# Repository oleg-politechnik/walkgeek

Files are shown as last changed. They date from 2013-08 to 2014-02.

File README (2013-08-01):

= About walkgeek ===============================================================

This is walkgeek, another portable music player based upon STM32F4-Discovery
board hardware, which contains STM32F407VGT6 microcontroller and CS43L22 audio
codec. For now, it can play MP3 and Opus files.

The goal of this project is to create a fully functional yet very simple
portable player, optimized for easy navigation across a lot of pretty long audio
files (podcasts).

= Hardware =====================================================================

There are 2 pretty similar HW platforms supported (or rather variations of a
one platform) called N1100 and F4DISCOVERY.

--- F4DISCOVERY ----------------------------------------------------------------

This platform is represented by STM32F4-Discovery board. It gives you an easy
way to try out and develop walkgeek. No HW modifications are necessary in a very
basic case. You only need to put some audio files supported by walkgeek on a USB
Flash drive and attach in to the USB Micro connector (CN5). User interface is
limited to a on-board "User" button which acts as button "3", and 4 leds:
 - Red means no Flash drive connected;
 - Green means Flash drive has enumerated and Player is started;
 - Orange means Player is stopped or loading current track;
 - Blue (blinking) means Player is playing current track.

--- N1100 ----------------------------------------------------------------------

There is also a more portable HW version that fits into Nokia 1100 cell phone
case. Design resources for it are also available in a pcb/ directory of this
project in EAGLE CAD format.

= Software =====================================================================

1. Checkout the latest version of the source code by following the instructions
   here: http://code.google.com/p/walkgeek/source/checkout

2. In order to build the source code, you need:
 - Git
 - CMake of a version of 2.8.4 or higher.
 - ARM GNU Toolchain: CodeSourcery, Linaro, etc.
 
3. You probably will find useful to have openocd as a gdb server which supports
   many cheap JTAG probes, including STLink v2 which is found in all the
   Discovery boards by ST.

= Example steps for Linux-based desktop ========================================

1. Checkout latest version of player's source code.

$ git clone 

2. It seems that CMake doesn't like embedded arm gnu toolchains (which is the
   case for at least CodeSourcery and Linaro on Ubuntu GNU/Linux) and shows
   errors at the project configure stage. You may solve them by typing: 

$ cd walkgeek
$ sudo ./patch_cmake.sh

   Dollar sign stands for command line prompt, do not type it.
   Please note that on OS other than GNU/Linux it may be different file or even
   may be unnecessary. Probably there is more proper way but this one has worked
   for me.

3. You should be at this moment in walkgeek directory. Type:

$ mkdir Build
$ cd Build

4. Next step is to invoke cmake in order to generate Makefiles. You can specify
   a list of parameters where syntax for each item is -D%param_name%=%param_value%.
   Among other standard cmake parameters, you can specify:
   - TOOLCHAIN_PREFIX -- full path to the root directory of your toolchain.
     Default is $ENV{HOME}/Local/gcc-arm-none-eabi-4_6-2012q2
   - TARGET_TRIPLET -- prefic for toolchain programs, default is arm-none-eabi.
   - STM32_USBLib_DIR -- full path to the STM32 USB Host Device Lib.
     Default is ${CMAKE_SOURCE_DIR}/bsp/3rd_party/STM32_USB-Host-Device_Lib_V2.1.0
   - CMAKE_BUILD_TYPE -- Release or Debug or others (please refer to the CMake
     documentation). Default is Debug.

   - PLATFORM -- choose one of the supported HW platforms: N1100, F4DISCOVERY,
     SIMULATOR (see below). Default is N1100.
   - PROFILING -- enable measurement of the CPU consumption of the audio codecs.
     1 enables, 0 disables. Default is 0.
   - ENABLE_TRACE -- enable trace() functions output via USB CDC. Default is 0.
   - USE_MP3 -- enable MP3 support. Default is 0.
   - RPROG_OHM -- if your platform is N1100, this is the value of resistor
     which sets LTC4054 charge current. Default is 2000.
   - SD_CARD_FILE -- if your platform is SIMULATOR, enter a full path to the
     file which contains FAT file system. See below for details. No default here.

   So if your toolchain and paths are the same, you don't need to specify all of
   them. In this example the default values are passed explicitly.

$ cmake -DTOOLCHAIN_PREFIX=/home/oleg/Local/CodeSourcery/Sourcery_CodeBench_Lite_for_ARM_EABI \
-DUSE_MP3=1 ../ -G"Unix Makefiles"

$ make

   Now you can build .hex, .bin or .dis (disassembly) files

$ make walkgeek.hex

   My Ubuntu even auto-completes Makefile targets.

6. (Optional) You can also debug it. Open one console, cd to the walkgeek's
   source root dir and

$ openocd -f openocd_luminary.cfg

   Switch to another console, cd to the walkgeek's source root dir and

$ arm-none-eabi-gdb --quiet --tui -x debug.gdb

= SIMULATOR ====================================================================

  There's a way to launch walkgeek on your PC (currently only POSIX OS'es are
  supported, at least GNU/Linux). PCM Audio output is not yet implemented.
  But console IO works and keyboard is simulated via stdin (just press a key
  and hit enter). If you press a number of keys and press enter, each of them
  will be handled consequently. Also, SD card IO simulation works, so that
  FAT FS module of walkgeek sees no difference compared to real HW. The idea is
  to manually create a file of some MB of a size, create FAT FS inside it
  (just like if it were an SD card), mount it, put some audio or whatever files
  in it and feed it to walkgeek application.

1. To do it, first create a file (this example will create a
   bs*count=128 MB file)

 $ dd if=/dev/zero of=sd_card.bin bs=1024 count=131072
 
2. Make FAT FS here
 
 $ /sbin/mkdosfs -F 16 sd_card.bin
 
3. Mount it
 
 $ mkdir fatmount
 $ sudo mount -t vfat -o umask=0000 -o loop sd_card.bin fatmount
 
4. Put some files into fatmount/ dir.

5. Unmount it in order to drain write buffers.

 $ sudo umount fatmount

6. When launching CMake (see above), choose -DPLATFORM=SIMULATOR -D%path-to%/sd_card.bin

  This is a good way to debug higher-level algorithms (for example, Navigator
  module was tested that way).

Thank you for your attention.

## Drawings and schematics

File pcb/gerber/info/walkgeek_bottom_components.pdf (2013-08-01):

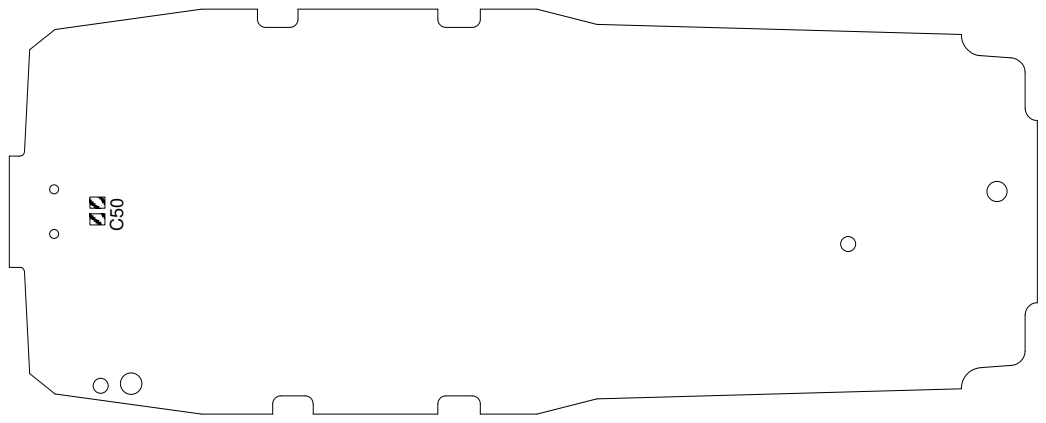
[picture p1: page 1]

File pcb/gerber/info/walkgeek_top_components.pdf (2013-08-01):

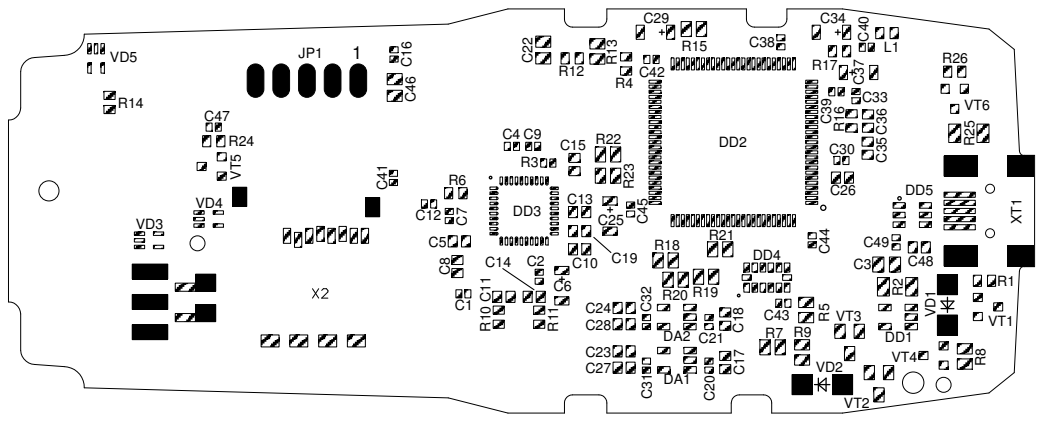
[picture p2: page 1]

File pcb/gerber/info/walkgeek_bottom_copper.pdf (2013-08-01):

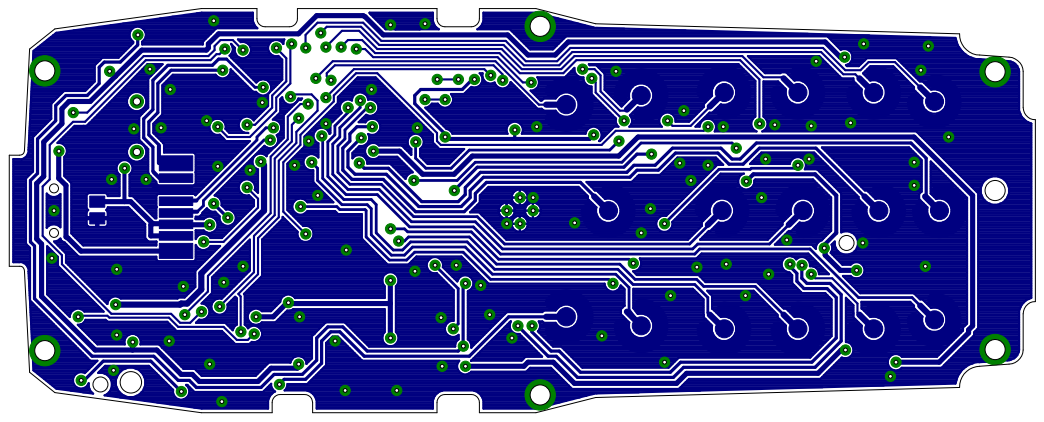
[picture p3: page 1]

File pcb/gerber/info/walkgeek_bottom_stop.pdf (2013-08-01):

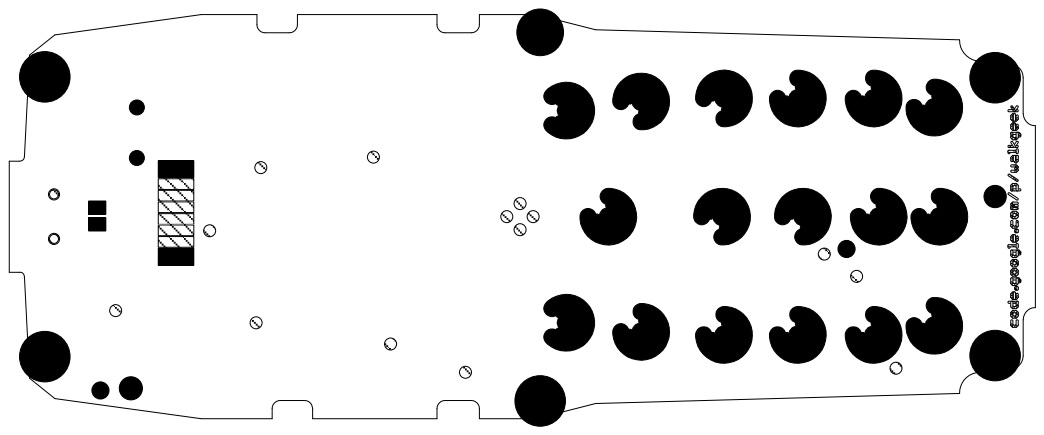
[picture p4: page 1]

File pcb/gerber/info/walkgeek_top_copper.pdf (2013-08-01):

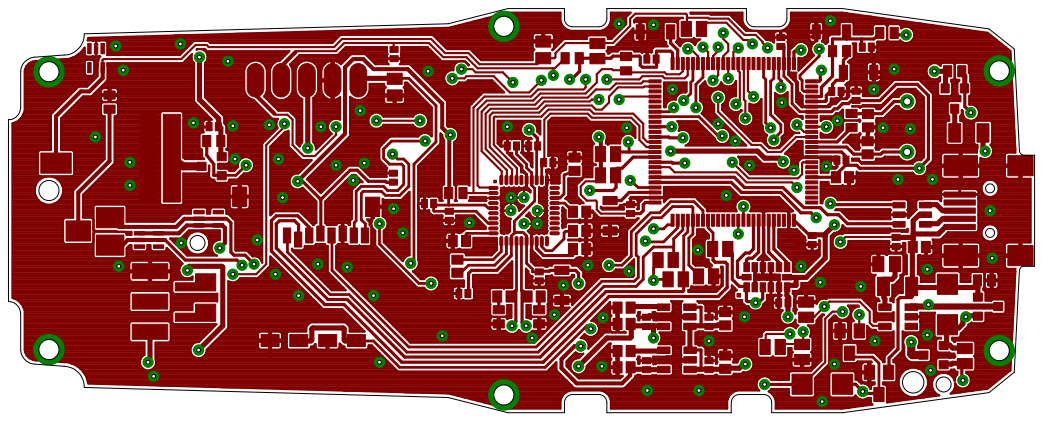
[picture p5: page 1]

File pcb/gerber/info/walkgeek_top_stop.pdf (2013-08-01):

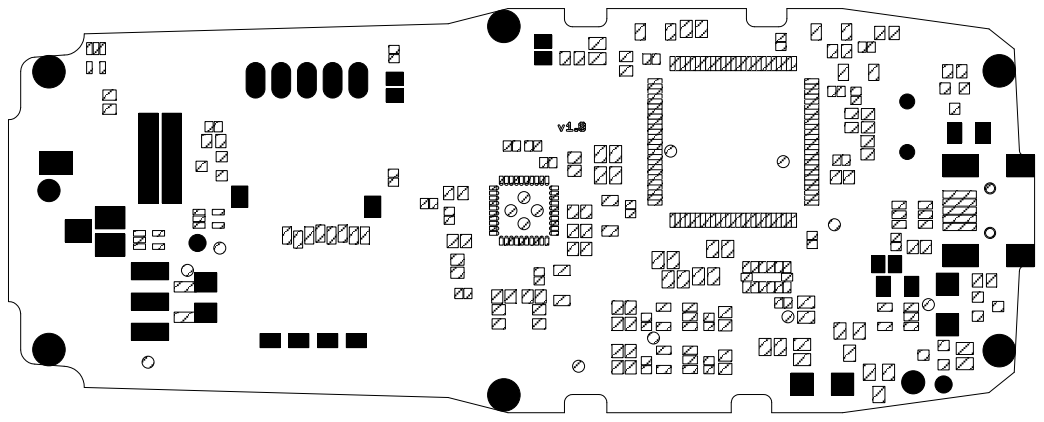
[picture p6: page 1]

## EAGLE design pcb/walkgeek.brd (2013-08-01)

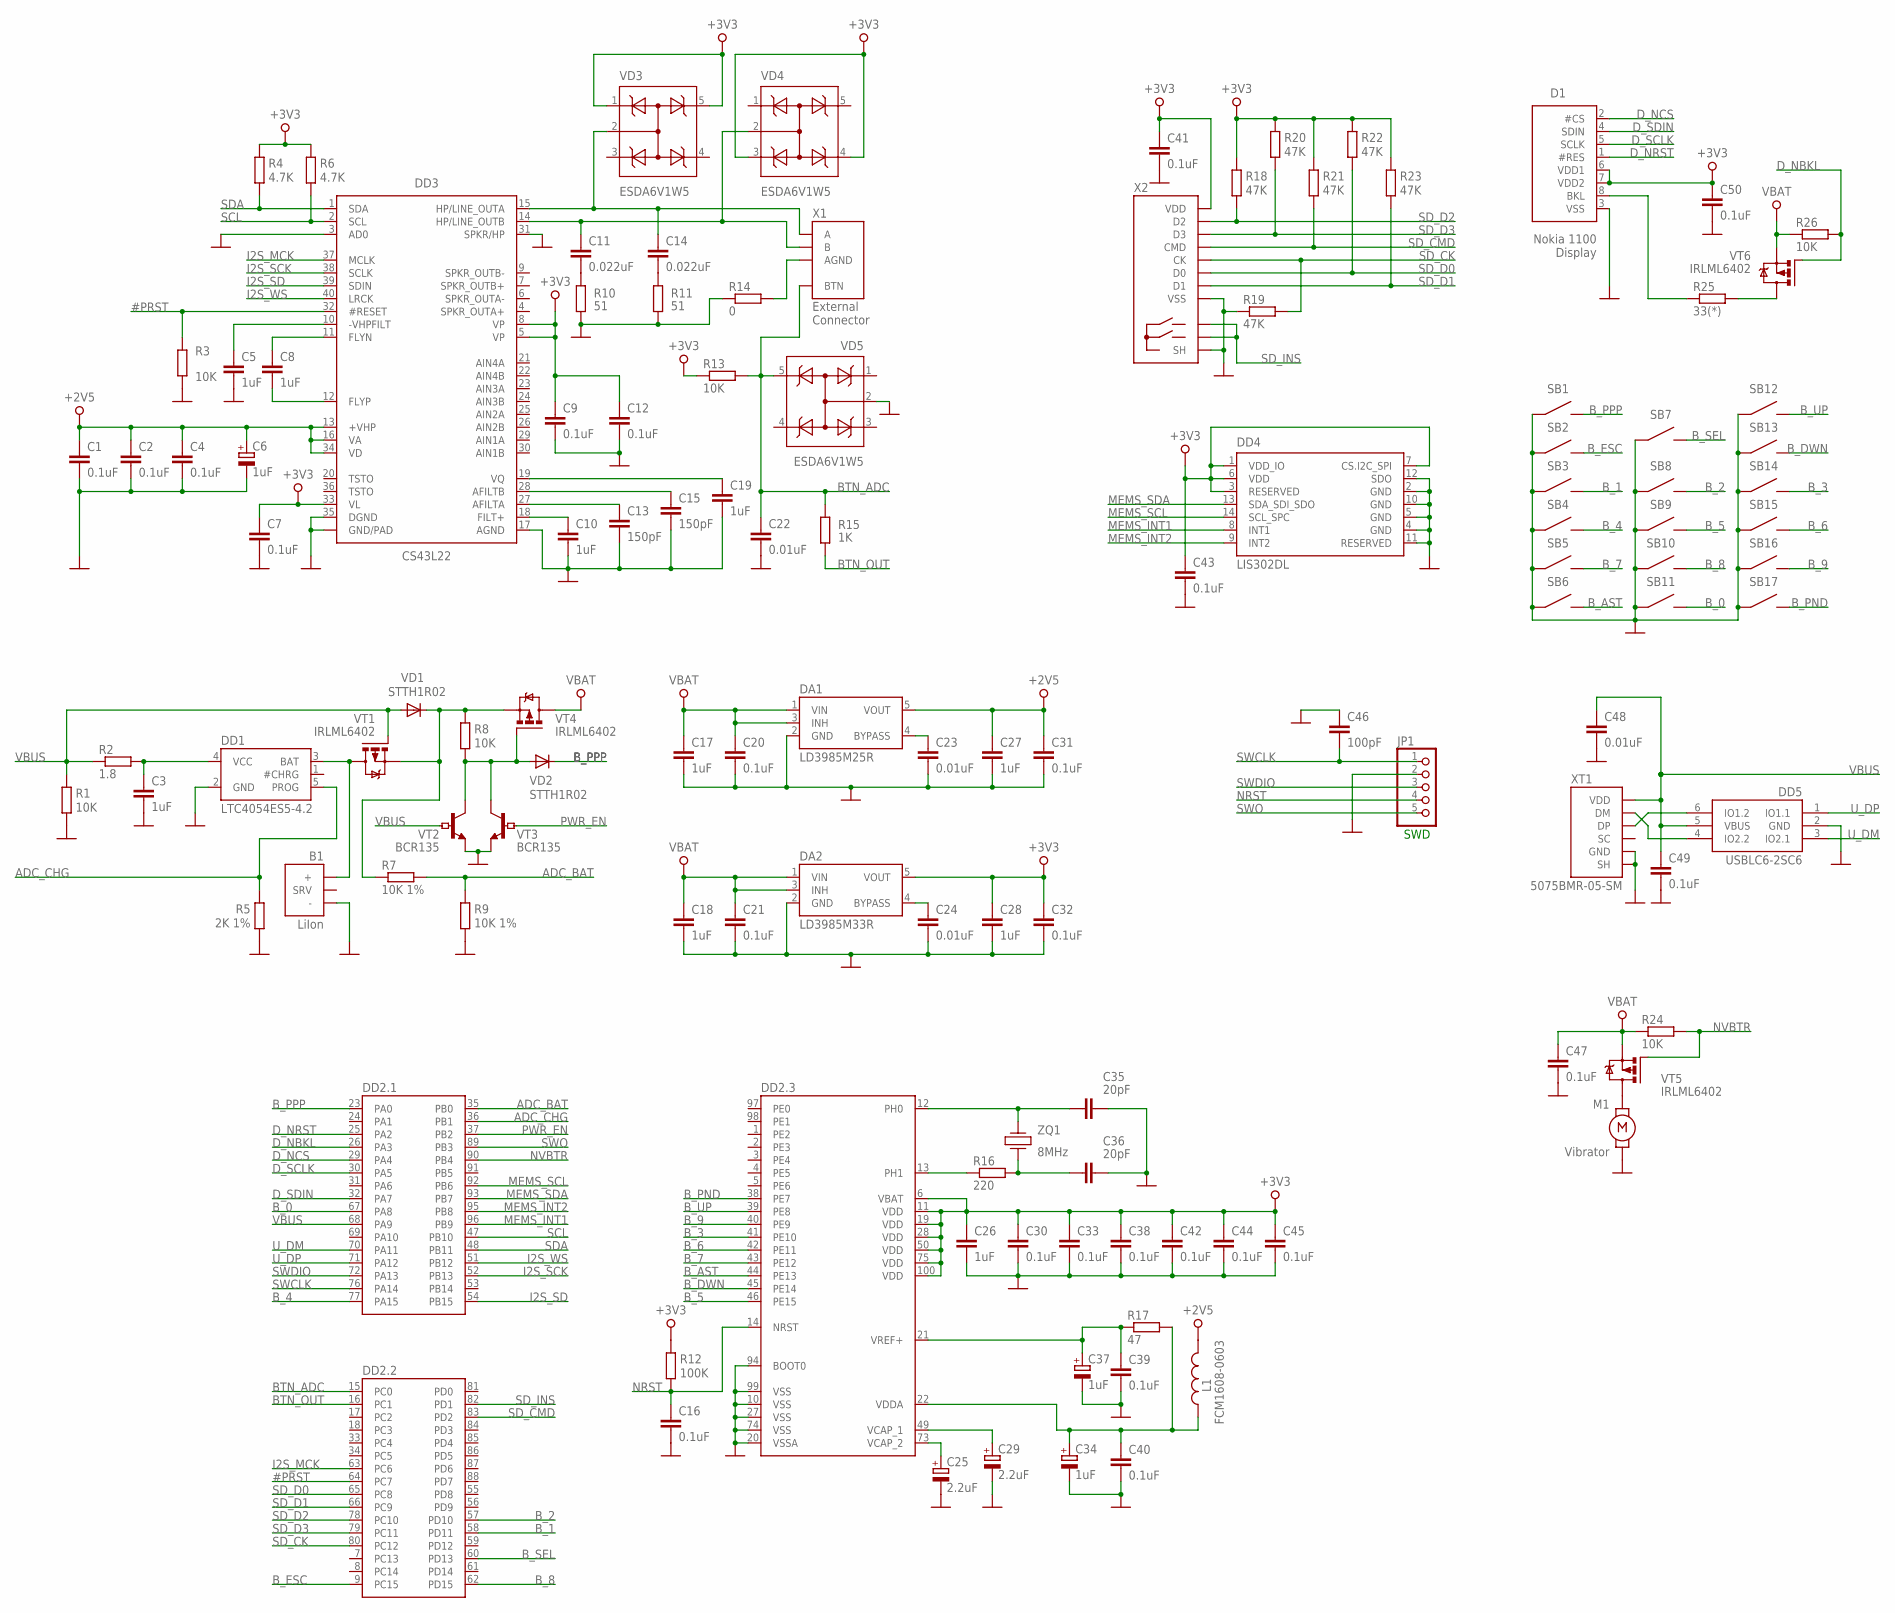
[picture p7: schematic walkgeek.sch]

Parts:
B1: NOKIA1100_BATTERY_CONN
C1, C2, C4, C7, C9, C12, C16, C20, C21, C30, C31, C32, C33, C38, C39, C40, C41, C42, C43, C44, C45, C47, C49: 0.1uF; C0402
C3: 1uF; C0805
C5, C8, C10, C17, C18, C19, C26, C27, C28: 1uF; C0603
C6, C34, C37: 1uF; SMC_A
C11, C14: 0.022uF; C0603
C13, C15: 150pF; C0603
C22: 0.01uF; C0805
C23, C24, C48: 0.01uF; C0603
C25, C29: 2.2uF; SMC_A
C35, C36: 20pF; C0603
C46: 100pF; C0805
C50: 0.1uF; C0805
D1: NOKIA1100_DISP
DA1: LD3985M25R; TSOT23-5
DA2: LD3985M33R; TSOT23-5
DD1: LTC4054ES5-4.2; TSOT23-5
DD2: STM32F4XXVXT; LQFP100
DD3: CS43L22; QFN40-6X6
DD4: LIS302DL; LGA14
DD5: USBLC6-2SC6; SOT23-6L
JP1: PINHD-1X5; 1X05/90_FLAT
L1: FCM1608-0603; R0603
M1: NOKIA1100_VIBRATOR
R1, R24, R26: 10K; R0603
R2: 1.8; R1206
R3: 10K; R0402
R4, R6: 4.7K; R0603
R5: 2K 1%; R0805
R7, R9: 10K 1%; R0805
R8, R13: 10K; R0805
R10, R11: 51; R0603
R12: 100K; R0603
R14: 0; R0603
R15: 1K; R0805
R16: 220; R0603
R17: 47; R0603
R18, R19, R20, R21, R22, R23: 47K; R0805
R25: 33(*); R1206
SB1, SB2, SB3, SB4, SB5, SB6, SB7, SB8, SB9, SB10, SB11, SB12, SB13, SB14, SB15, SB16, SB17: NOKIA1100_KEY_PAD_0
VD1, VD2: STTH1R02; SMA
VD3, VD4, VD5: ESDA6V1W5; SOT323-5L
VT1, VT4, VT5, VT6: IRLML6402; MICRO3
VT2, VT3: BCR135; SOT23-BEC
X1: NOKIA1100_EXT_CONN
X2: MICROSD_CONN; TFC-WPCE-08
XT1: 5075BMR-05-SM; 32005-201
ZQ1: 8MHz; QUARTZ_5MM

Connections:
#PRST: DD2.64 (PC7), DD3.32 (#RESET), R3.2
+2V5: C1.1, C2.1, C4.1, C6.+, C27.1, C31.1, DA1.5 (VOUT), DD3.13 (+VHP), DD3.16 (VA), DD3.34 (VD), L1.1
+3V3: C7.1, C9.1, C12.1, C26.1, C28.1, C30.1, C32.1, C33.1, C38.1, C41.1, C42.1, C43.1, C44.1, C45.1, C50.1, D1.6 (VDD1), D1.7 (VDD2), DA2.5 (VOUT), DD2.6 (VBAT), DD2.11 (VDD), DD2.19 (VDD), DD2.28 (VDD), DD2.50 (VDD), DD2.75 (VDD), DD2.100 (VDD), DD3.5 (VP), DD3.8 (VP), DD3.33 (VL), DD4.1 (VDD_IO), DD4.3 (RESERVED), DD4.6 (VDD), DD4.7 (CS.I2C_SPI), R4.2, R6.2, R12.2, R13.1, R18.2, R20.2, R21.2, R22.2, R23.2, VD3.1, VD3.5, VD4.3, VD4.4, X2.VDD
ADC_BAT: DD2.35 (PB0), R7.2, R9.2
ADC_CHG: DD1.5 (PROG), DD2.36 (PB1), R5.2
BTN_ADC: C22.1, DD2.15 (PC0), R13.2, R15.2, VD5.5, X1.BTN
BTN_OUT: DD2.16 (PC1), R15.1
B_0: DD2.67 (PA8), SB11.INNER
B_1: DD2.58 (PD11), SB3.INNER
B_2: DD2.57 (PD10), SB8.INNER
B_3: DD2.41 (PE10), SB14.INNER
B_4: DD2.77 (PA15), SB4.INNER
B_5: DD2.46 (PE15), SB9.INNER
B_6: DD2.42 (PE11), SB15.INNER
B_7: DD2.43 (PE12), SB5.INNER
B_8: DD2.62 (PD15), SB10.INNER
B_9: DD2.40 (PE9), SB16.INNER
B_AST: DD2.44 (PE13), SB6.INNER
B_DWN: DD2.45 (PE14), SB13.INNER
B_ESC: DD2.9 (PC15), SB2.INNER
B_PND: DD2.38 (PE7), SB17.INNER
B_PPP: DD2.23 (PA0), SB1.INNER, VD2.C
B_SEL: DD2.60 (PD13), SB7.INNER
B_UP: DD2.39 (PE8), SB12.INNER
D_NBKL: DD2.26 (PA3), R26.2, VT6.1 (G)
D_NCS: D1.2 (#CS), DD2.29 (PA4)
D_NRST: D1.1 (#RES), DD2.25 (PA2)
D_SCLK: D1.5 (SCLK), DD2.30 (PA5)
D_SDIN: D1.4 (SDIN), DD2.32 (PA7)
GND: B1.-, C1.2, C2.2, C3.2, C4.2, C5.2, C6.-, C7.2, C9.2, C10.2, C12.2, C13.2, C15.2, C16.2, C17.2, C18.2, C19.2, C20.2, C21.2, C22.2, C23.2, C24.2, C25.-, C26.2, C27.2, C28.2, C29.-, C30.2, C31.2, C32.2, C33.2, C34.-, C35.2, C36.2, C37.-, C38.2, C39.2, C40.2, C41.2, C42.2, C43.2, C44.2, C45.2, C46.1, C47.2, C48.2, C49.2, C50.2, D1.3 (VSS), DA1.2 (GND), DA2.2 (GND), DD1.2 (GND), DD2.10 (VSS), DD2.20 (VSSA), DD2.27 (VSS), DD2.74 (VSS), DD2.94 (BOOT0), DD2.99 (VSS), DD3.3 (AD0), DD3.17 (AGND), DD3.31 (SPKR/HP), DD3.35 (DGND), DD3.EXP@3 (GND/PAD), DD3.EXP@4 (GND/PAD), DD3.EXP@5 (GND/PAD), DD3.EXP@9 (GND/PAD), DD4.2 (GND), DD4.4 (GND), DD4.5 (GND), DD4.10 (GND), DD4.11 (RESERVED), DD4.12 (SDO), DD5.2 (GND), JP1.2, M1.2, R1.1, R3.1, R5.1, R9.1, R10.1, R11.1, R14.1, R19.1, SB1.OUTER, SB1.OUTER1 (OUTER), SB2.OUTER, SB2.OUTER1 (OUTER), SB3.OUTER, SB3.OUTER1 (OUTER), SB4.OUTER, SB4.OUTER1 (OUTER), SB5.OUTER, SB5.OUTER1 (OUTER), SB6.OUTER, SB6.OUTER1 (OUTER), SB7.OUTER, SB7.OUTER1 (OUTER), SB8.OUTER, SB8.OUTER1 (OUTER), SB9.OUTER, SB9.OUTER1 (OUTER), SB10.OUTER, SB10.OUTER1 (OUTER), SB11.OUTER, SB11.OUTER1 (OUTER), SB12.OUTER, SB12.OUTER1 (OUTER), SB13.OUTER, SB13.OUTER1 (OUTER), SB14.OUTER, SB14.OUTER1 (OUTER), SB15.OUTER, SB15.OUTER1 (OUTER), SB16.OUTER, SB16.OUTER1 (OUTER), SB17.OUTER, SB17.OUTER1 (OUTER), VD5.2, VT2.E, VT3.E, X2.SH1 (SH), X2.SH2 (SH), X2.SH3 (SH), X2.SH4 (SH), X2.VSS, XT1.5 (GND), XT1.M1 (SH), XT1.M2 (SH), XT1.M3 (SH), XT1.M4 (SH)
I2S_MCK: DD2.63 (PC6), DD3.37 (MCLK)
I2S_SCK: DD2.52 (PB13), DD3.38 (SCLK)
I2S_SD: DD2.54 (PB15), DD3.39 (SDIN)
I2S_WS: DD2.51 (PB12), DD3.40 (LRCK)
MEMS_INT1: DD2.96 (PB9), DD4.8 (INT1)
MEMS_INT2: DD2.95 (PB8), DD4.9 (INT2)
MEMS_SCL: DD2.92 (PB6), DD4.14 (SCL_SPC)
MEMS_SDA: DD2.93 (PB7), DD4.13 (SDA_SDI_SDO)
unnamed: D1.8 (BKL), R25.1
unnamed: C10.1, DD3.18 (FILT+)
unnamed: C13.1, DD3.27 (AFILTA)
unnamed: C15.1, DD3.28 (AFILTB)
unnamed: C19.1, DD3.19 (VQ)
unnamed: C11.1, DD3.14 (HP/LINE_OUTB), VD4.2, X1.B
unnamed: C14.1, DD3.15 (HP/LINE_OUTA), VD3.2, X1.A
unnamed: C8.1, DD3.11 (FLYN)
unnamed: C8.2, DD3.12 (FLYP)
unnamed: C5.1, DD3.10 (-VHPFILT)
unnamed: R14.2, X1.AGND
unnamed: C11.2, R10.2
unnamed: C14.2, R11.2
unnamed: M1.1, VT5.3 (D)
unnamed: C3.1, DD1.4 (VCC), R2.2
unnamed: R7.1, R8.2, VD1.C, VT1.2 (S), VT4.2 (S)
unnamed: DD2.13 (PH1), R16.1
unnamed: R25.2, VT6.3 (D)
unnamed: R8.1, VD2.A, VT2.C, VT3.C, VT4.1 (G)
unnamed: DD5.6 (IO1.2), XT1.3 (DP)
unnamed: DD5.4 (IO2.2), XT1.2 (DM)
unnamed: C25.+, DD2.73 (VCAP_2)
unnamed: C35.1, DD2.12 (PH0), ZQ1.P$1
unnamed: C24.1, DA2.4 (BYPASS)
unnamed: C23.1, DA1.4 (BYPASS)
unnamed: C29.+, DD2.49 (VCAP_1)
unnamed: C34.+, C40.1, DD2.22 (VDDA), L1.2, R17.2
unnamed: C37.+, C39.1, DD2.21 (VREF+), R17.1
unnamed: C36.1, R16.2, ZQ1.P$2
NRST: C16.1, DD2.14 (NRST), JP1.4, R12.1
NVBTR: DD2.90 (PB4), R24.2, VT5.1 (G)
PWR_EN: DD2.37 (PB2), VT3.B
SCL: DD2.47 (PB10), DD3.2 (SCL), R6.1
SDA: DD2.48 (PB11), DD3.1 (SDA), R4.1
SD_CK: DD2.80 (PC12), R19.2, X2.CLK (CK)
SD_CMD: DD2.83 (PD2), R21.1, X2.CMD
SD_D0: DD2.65 (PC8), R22.1, X2.DAT0 (D0)
SD_D1: DD2.66 (PC9), R23.1, X2.DAT1 (D1)
SD_D2: DD2.78 (PC10), R18.1, X2.DAT2 (D2)
SD_D3: DD2.79 (PC11), R20.1, X2.CD/DAT3 (D3)
SD_INS: DD2.82 (PD1), X2.SNS1, X2.SNS2
SWCLK: C46.2, DD2.76 (PA14), JP1.1
SWDIO: DD2.72 (PA13), JP1.3
SWO: DD2.89 (PB3), JP1.5
U_DM: DD2.70 (PA11), DD5.3 (IO2.1)
U_DP: DD2.71 (PA12), DD5.1 (IO1.1)
VBAT: C17.1, C18.1, C20.1, C21.1, C47.1, DA1.1 (VIN), DA1.3 (INH), DA2.1 (VIN), DA2.3 (INH), R24.1, R26.1, VT4.3 (D), VT5.2 (S), VT6.2 (S)
VBAT0: B1.+, DD1.3 (BAT), VT1.3 (D)
VBUS: C48.1, C49.1, DD2.68 (PA9), DD5.5 (VBUS), R1.2, R2.1, VD1.A, VT1.1 (G), VT2.B, XT1.1 (VDD)

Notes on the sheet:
SWD

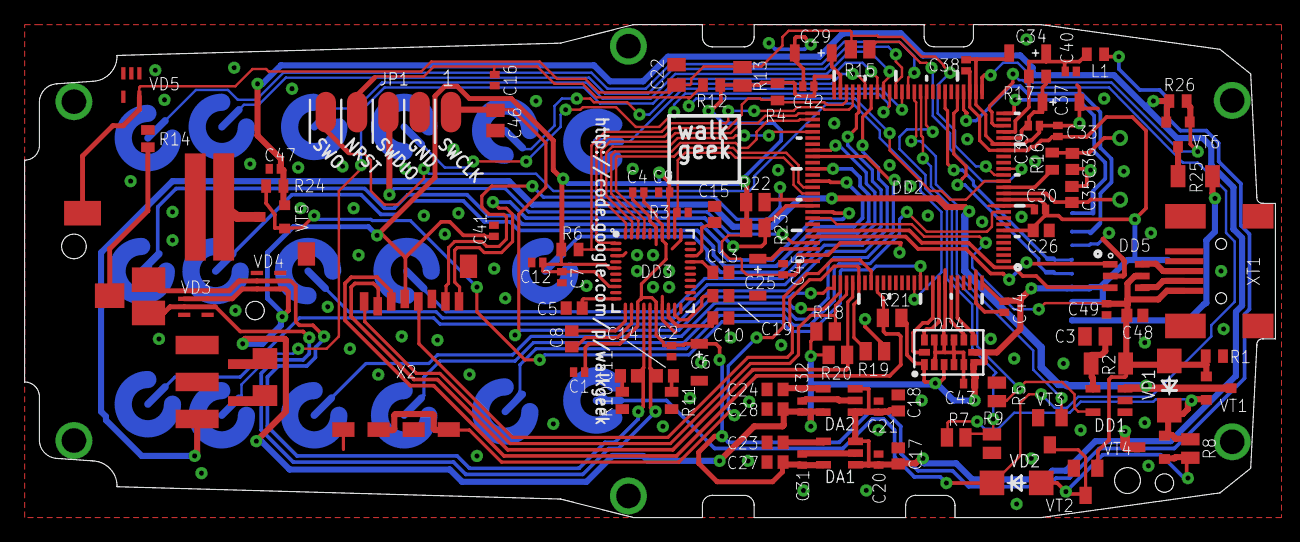
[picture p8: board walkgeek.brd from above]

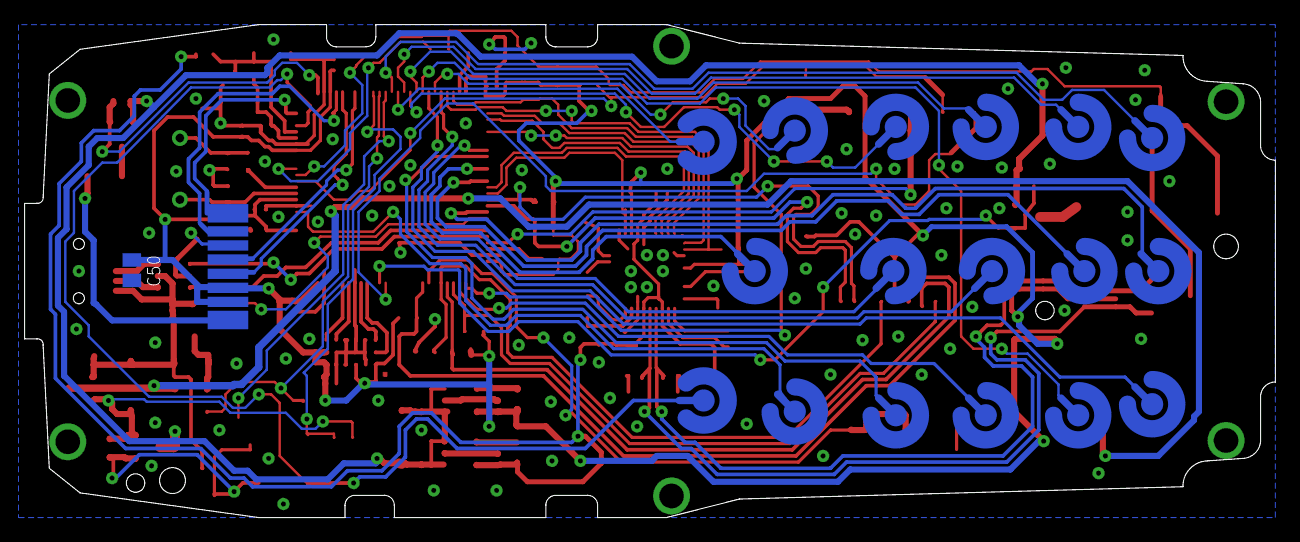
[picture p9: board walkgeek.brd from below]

Board: 2 copper layers, 101.5 x 40.0 mm, 120 parts (19 on the bottom side), 87 nets.

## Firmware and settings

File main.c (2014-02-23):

/*
 * main.c
 *
 * Copyright (c) 2012, 2013, 2014 Oleg Tsaregorodtsev
 * All rights reserved.
 *
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
 * THIS SOFTWARE IS PROVIDED BY THE COPYRIGHT HOLDERS AND CONTRIBUTORS "AS IS"
 * AND ANY EXPRESS OR IMPLIED WARRANTIES, INCLUDING, BUT NOT LIMITED TO, THE
 * IMPLIED WARRANTIES OF MERCHANTABILITY AND FITNESS FOR A PARTICULAR PURPOSE
 * ARE DISCLAIMED. IN NO EVENT SHALL THE COPYRIGHT HOLDER OR CONTRIBUTORS BE
 * LIABLE FOR ANY DIRECT, INDIRECT, INCIDENTAL, SPECIAL, EXEMPLARY, OR
 * CONSEQUENTIAL DAMAGES (INCLUDING, BUT NOT LIMITED TO, PROCUREMENT OF
 * SUBSTITUTE GOODS OR SERVICES; LOSS OF USE, DATA, OR PROFITS; OR BUSINESS
 * INTERRUPTION) HOWEVER CAUSED AND ON ANY THEORY OF LIABILITY, WHETHER IN
 * CONTRACT, STRICT LIABILITY, OR TORT (INCLUDING NEGLIGENCE OR OTHERWISE)
 * ARISING IN ANY WAY OUT OF THE USE OF THIS SOFTWARE, EVEN IF ADVISED OF
 * THE POSSIBILITY OF SUCH DAMAGE.
 */

/* Includes ~~~~~~~~~~~~~~~~~~~~~~~~~~~~~~~~~~~~~~~~~~~~~~~~~~~~~~~~~~~~~~~~~~*/
#include "FreeRTOS.h"
#include "task.h"
#include "queue.h"
#include "timers.h"

#include "system.h"
#include "keypad.h"
#include "player.h"
#include "ui.h"
#include "powermanager.h"
#include "audio_if.h"
#include "cpu_config.h"

/* Imported variables ~~~~~~~~~~~~~~~~~~~~~~~~~~~~~~~~~~~~~~~~~~~~~~~~~~~~~~~~*/
extern void prvPlayerTask(void *);
extern void prvUiTask(void *);

/* Private define ~~~~~~~~~~~~~~~~~~~~~~~~~~~~~~~~~~~~~~~~~~~~~~~~~~~~~~~~~~~~*/
/* Private typedef ~~~~~~~~~~~~~~~~~~~~~~~~~~~~~~~~~~~~~~~~~~~~~~~~~~~~~~~~~~~*/
/* Private macro ~~~~~~~~~~~~~~~~~~~~~~~~~~~~~~~~~~~~~~~~~~~~~~~~~~~~~~~~~~~~~*/
/* Private variables ~~~~~~~~~~~~~~~~~~~~~~~~~~~~~~~~~~~~~~~~~~~~~~~~~~~~~~~~~*/
volatile SystemState_Typedef SystemState = SS_START;
static bool debug_mode = false;
static bool can_sleep = false;
static bool was_player_once_upon_a_time = false;

static xQueueHandle xSystemStateQueue;
static xTimerHandle xEnterLowPowerModeTimer;

#ifdef ENABLE_TRACE
static char *stateNames[] =
{
        "START",
        "PLAYER",
#ifdef USE_DEVICE_MODE
        "USB_MSC",
#endif
        "",
        "SHUTDOWN"
};
#endif

/* Private function prototypes ~~~~~~~~~~~~~~~~~~~~~~~~~~~~~~~~~~~~~~~~~~~~~~~*/
static void SetState(SystemState_Typedef NewState);

/* Private functions ~~~~~~~~~~~~~~~~~~~~~~~~~~~~~~~~~~~~~~~~~~~~~~~~~~~~~~~~~*/

static void System_EnterLowPowerModeCallback(xTimerHandle xTimer)
{
  if (!debug_mode)
  {
    can_sleep = true;
  }
}

static void prvInitTask(void *pvParameters)
{
  xSystemStateQueue = xQueueCreate( mainSYSTEM_STATE_QUEUE_SIZE,
          sizeof( SystemState_Typedef ) );

  BSP_Keypad_Init();

  UI_PreInit();

#ifdef HAS_BATTERY
  PowerManager_Init();
  PowerManager_MainThread();

  if (PowerManager_GetState() != PM_ONLINE)
  {
#ifdef HAS_BATTERY
    u32 delay = 0;

    while (delay < /*configUI_LONG_PRESS_TIMEOUT_MS*/ 2000 / portTICK_RATE_MS)
    {
      if (!BSP_Keypad_GetKeyStatus(KEY_PPP))
      {
        BSP_PowerDisable();
      }

      vTaskDelay(configUI_PRESS_TICK_MS);
      delay += configUI_PRESS_TICK_MS;
    }
#endif

    System_SetState(SS_PLAYER);
  }
  else
  {
    System_SetState(debug_mode ? SS_PLAYER : SS_USB_MSC);
  }
#else
#ifdef USE_HOST_MODE
  USB_Host_Init();
#endif
  System_SetState(SS_PLAYER);
#endif

  Display_Init(ENABLE);

  xTaskCreate(prvUiTask, (signed portCHAR *) "UI",
          mainUI_TASK_STACK_SIZE, NULL, mainUI_TASK_PRIORITY, NULL);

  xTaskCreate(prvPlayerTask, (signed portCHAR *) "Player",
          mainPLAYER_TASK_STACK_SIZE, NULL, mainPLAYER_TASK_PRIORITY, NULL);

  {
    xEnterLowPowerModeTimer = xTimerCreate(
            (signed portCHAR *) "Enter Low Power Mode Timer",
            10000 / portTICK_RATE_MS, pdFALSE,
            (void *) System_EnterLowPowerModeCallback,
            System_EnterLowPowerModeCallback);
    xTimerStart(xEnterLowPowerModeTimer, configTIMER_API_TIMEOUT_MS);
  }

  while (1)
  {
    SystemState_Typedef NewSystemState;

    if (xQueueReceive(xSystemStateQueue, &(NewSystemState), 100 / portTICK_RATE_MS))
    {
      SetState(NewSystemState);
    }

#ifdef HAS_BATTERY
    PowerManager_MainThread();
#endif
  }
}

#ifdef USE_DEVICE_MODE
void System_VbusApplied(void)
{
  if (SystemState != SS_USB_MSC)
  {
    USB_CDC_Init();
    return;
  }
}

void System_VbusDetached(void)
{
  //XXX de-init USB properly?
  //the need of vbus sensing (st stack may be de-initializing smth)
  USB_DeInit();
}
#endif

void System_SetState(SystemState_Typedef NewState)
{
#ifdef USE_DEVICE_MODE
  if (NewState == SS_PLAYER)
  {
    was_player_once_upon_a_time = true;
  }

#ifdef HAS_BATTERY
  if (NewState == SS_USB_MSC && PowerManager_GetState() != PM_ONLINE)
  {
    return;
  }
#endif
#endif

  xQueueSend( xSystemStateQueue, ( void * ) &NewState, portMAX_DELAY );
}

void System_SetStateFomISR(SystemState_Typedef NewState)
{
#ifdef USE_DEVICE_MODE
  if (NewState == SS_PLAYER)
  {
    was_player_once_upon_a_time = true;
  }

#ifdef HAS_BATTERY
  if (NewState == SS_USB_MSC && PowerManager_GetState() != PM_ONLINE)
  {
    return;
  }
#endif
#endif

  xQueueSendFromISR( xSystemStateQueue, ( void * ) &NewState, NULL );
}

/*
 * Can only be called from the main thread
 */
void SetState(SystemState_Typedef NewState)
{
  trace("system: leaving state %s\n", stateNames[SystemState]);

  if (NewState == SS_SHUTDOWN)
  {
    Vibrator_SendSignal(30);
  }

  switch (SystemState)
  {
    case SS_PLAYER:
      Player_AsyncCommand(PC_SAVE_CURRENT_DIR, 0);
      Player_AsyncCommand(PC_DEINIT, 0);
      break;

#ifdef USE_DEVICE_MODE
    case SS_USB_MSC:
      USB_DeInit();
      break;
#endif

    default:
      break;
  }

  trace("system: entering state %s\n", stateNames[NewState]);

  UI_SetVariable(VAR_SystemState, SystemState, NewState);

  switch (NewState)
  {
    case SS_SHUTDOWN:
      BSP_PowerDisable();
      break;

    case SS_PLAYER:
      BSP_PowerEnable();
//      was_player_once_upon_a_time = true;
      Player_AsyncCommand(PC_INIT, 0);
      break;

#ifdef USE_DEVICE_MODE
    case SS_USB_MSC:
      USB_MSC_Init();
      break;
#endif

    case SS_USB_DISCONNECT:
      if (was_player_once_upon_a_time)
      {
        System_SetState(SS_PLAYER);
      }
      else
      {
        System_SetState(SS_SHUTDOWN);
      }
      break;

    default:
      break;
  }
}

int main(void)
{
  CPU_PreInit();

  xTaskCreate(prvInitTask, (signed portCHAR *) "Init", mainINIT_TASK_STACK_SIZE,
          NULL, mainINIT_TASK_PRIORITY, NULL);

  /* Start the scheduler. */
  vTaskStartScheduler();

  configASSERT(!"Fatal RTOS startup error");

  return 42;
}

void vApplicationIdleHook(void)
{
  if (can_sleep)
  {
    CPU_WaitForInterrupt();
  }
}

void vApplicationTickHook(void)
{
  Keypad_1msScan();
  BSP_StartADC();
}

void vApplicationMallocFailedHook(void)
{
  configASSERT(!"Malloc failed");
}

void vApplicationStackOverflowHook(xTaskHandle *pxTask,
    signed portCHAR *pcTaskName)
{
	configASSERT(!"Stack overflow");
}

#ifdef  USE_FULL_ASSERT
void assert_failed(char* file, uint32_t line, char* expr)
{
	/* User can add his own implementation to report the file name and line number,
	 ex: printf("Wrong parameters value: file %s on line %d\n", file, line) */

	vPortEnterCritical();

	char buf[256];

	//TODO: add application state

	Codec_Reset();

	Vibrator_Disable();

	Display_Init(DISABLE);

	if (file)
	{
		snprintf(buf, sizeof(buf),
				"EPIC FAIL!\nLine %i at %s:\n%s", (int) line, (char *) ((int) strrchr(file, '/') ? strrchr(file, '/') + 1 : file), expr);
		Display_String(0, 0, buf, true);
	}
	else
	{
		Display_String(0, 0, expr, true);
	}

	/* Infinite loop */
	while (1)
	{
		Display_MainCycle();

		if (BSP_Keypad_GetKeyStatus(KEY_PPP))
		{
			//Delay(10); //todo const
//      delay += 10;

//      if (delay < 1000) //todo const
//      {
			BSP_PowerDisable();
//      }
		}
		else
		{
//      delay = 0;
		}
	}
}
#endif

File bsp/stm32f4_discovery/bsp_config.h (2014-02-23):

/*
 * bsp_config.h
 *
 * Copyright (c) 2012, Oleg Tsaregorodtsev
 * All rights reserved.
 *
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
 * THIS SOFTWARE IS PROVIDED BY THE COPYRIGHT HOLDERS AND CONTRIBUTORS "AS IS"
 * AND ANY EXPRESS OR IMPLIED WARRANTIES, INCLUDING, BUT NOT LIMITED TO, THE
 * IMPLIED WARRANTIES OF MERCHANTABILITY AND FITNESS FOR A PARTICULAR PURPOSE
 * ARE DISCLAIMED. IN NO EVENT SHALL THE COPYRIGHT HOLDER OR CONTRIBUTORS BE
 * LIABLE FOR ANY DIRECT, INDIRECT, INCIDENTAL, SPECIAL, EXEMPLARY, OR
 * CONSEQUENTIAL DAMAGES (INCLUDING, BUT NOT LIMITED TO, PROCUREMENT OF
 * SUBSTITUTE GOODS OR SERVICES; LOSS OF USE, DATA, OR PROFITS; OR BUSINESS
 * INTERRUPTION) HOWEVER CAUSED AND ON ANY THEORY OF LIABILITY, WHETHER IN
 * CONTRACT, STRICT LIABILITY, OR TORT (INCLUDING NEGLIGENCE OR OTHERWISE)
 * ARISING IN ANY WAY OUT OF THE USE OF THIS SOFTWARE, EVEN IF ADVISED OF
 * THE POSSIBILITY OF SUCH DAMAGE.
 */

/* Define to prevent recursive inclusion ~~~~~~~~~~~~~~~~~~~~~~~~~~~~~~~~~~~~~*/
#ifndef BSP_CONFIG_H_
#define BSP_CONFIG_H_

/* Includes ~~~~~~~~~~~~~~~~~~~~~~~~~~~~~~~~~~~~~~~~~~~~~~~~~~~~~~~~~~~~~~~~~~*/
/* Exported defines ~~~~~~~~~~~~~~~~~~~~~~~~~~~~~~~~~~~~~~~~~~~~~~~~~~~~~~~~~~*/
#ifdef HAS_BATTERY
# define PWR_EN_GPIO                 GPIOB
# define PWR_EN_AHB1_CLK             RCC_AHB1Periph_GPIOB
# define PWR_EN_PIN                  GPIO_Pin_2
#endif

/* disp_1100 -----------------------------------------------------------------*/
#define DISP_1100_GPIO                   GPIOA
#define DISP_1100_GPIO_CLK               RCC_AHB1Periph_GPIOA

#define DISP_1100_PinSrc_RST             GPIO_PinSource2
#define DISP_1100_PinSrc_BKL             GPIO_PinSource3
#define DISP_1100_Pin_RST                GPIO_Pin_2
#define DISP_1100_Pin_BKL                GPIO_Pin_3

#ifdef N1100
# define DISP_1100_Pin_CS                 GPIO_Pin_4
#elif F4DISCOVERY
# define DISP_1100_Pin_CS                 GPIO_Pin_1
#endif

#define DISP_1100_Pin_SCK                GPIO_Pin_5
#define DISP_1100_Pin_MOSI               GPIO_Pin_7
#define DISP_1100_PinSrc_SCK             GPIO_PinSource5
#define DISP_1100_PinSrc_MOSI            GPIO_PinSource7

#define DISP_1100_SPI                    SPI1
#define DISP_1100_SPI_IRQ                SPI1_IRQn
#define DISP_1100_GPIO_AF_SPI            GPIO_AF_SPI1
#define DISP_1100_RCC_APB2Periph_SPI     RCC_APB2Periph_SPI1

#define Disp1100_IRQHandler             SPI1_IRQHandler

/* keyboard ------------------------------------------------------------------*/
#define KEY_DEBOUNCE_CYCLES             4

typedef struct {
  GPIO_TypeDef* GPIOx;
  uint8_t GPIO_PinSourcex;
  uint16_t RCC_AHB1Periph_GPIOx;
} KeyPin_Typedef;

#include "keypad.h"

/* Keep this in sync with KEY_Typedef */
#ifdef N1100
#define KEY_PIN_TYPEDEFS \
  { /* KEY_PPP      */ GPIOA, GPIO_PinSource0,  RCC_AHB1Periph_GPIOA}, \
  { /* KEY_C        */ GPIOC, GPIO_PinSource15, RCC_AHB1Periph_GPIOC}, \
  { /* KEY_SEL      */ GPIOD, GPIO_PinSource13, RCC_AHB1Periph_GPIOD}, \
  { /* KEY_UP       */ GPIOE, GPIO_PinSource8,  RCC_AHB1Periph_GPIOE}, \
  { /* KEY_DOWN     */ GPIOE, GPIO_PinSource14, RCC_AHB1Periph_GPIOE}, \
  { /* KEY_1        */ GPIOD, GPIO_PinSource11, RCC_AHB1Periph_GPIOD}, \
  { /* KEY_2        */ GPIOD, GPIO_PinSource10, RCC_AHB1Periph_GPIOD}, \
  { /* KEY_3        */ GPIOE, GPIO_PinSource10, RCC_AHB1Periph_GPIOE}, \
  { /* KEY_4        */ GPIOA, GPIO_PinSource15, RCC_AHB1Periph_GPIOA}, \
  { /* KEY_5        */ GPIOE, GPIO_PinSource15, RCC_AHB1Periph_GPIOE}, \
  { /* KEY_6        */ GPIOE, GPIO_PinSource11, RCC_AHB1Periph_GPIOE}, \
  { /* KEY_7        */ GPIOE, GPIO_PinSource12, RCC_AHB1Periph_GPIOE}, \
  { /* KEY_8        */ GPIOD, GPIO_PinSource15, RCC_AHB1Periph_GPIOD}, \
  { /* KEY_9        */ GPIOE, GPIO_PinSource9,  RCC_AHB1Periph_GPIOE}, \
  { /* KEY_ASTERICK */ GPIOE, GPIO_PinSource13, RCC_AHB1Periph_GPIOE}, \
  { /* KEY_0        */ GPIOA, GPIO_PinSource8,  RCC_AHB1Periph_GPIOA}, \
  { /* KEY_POUND    */ GPIOE, GPIO_PinSource7,  RCC_AHB1Periph_GPIOE}
#endif
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

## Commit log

2013-04-22 v1.0 pcb draft
    [walkgeek.brd, walkgeek.sch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]
2013-08-01 Initial source code commit (m4-player svn r9)
    [stm32f4x.cfg]
2013-08-01 Ported OPUS
    [walkgeek.brd, walkgeek.sch]
2013-08-01 player first/last file in current dir
2013-08-01 Added STM32F4DISCOVERY board port
2013-08-01 PowerManager fixes
    [walkgeek.brd, walkgeek.sch]
2013-08-01 Corrected pcb numbering and captions
    [walkgeek.brd, walkgeek.sch]
2013-08-01 Added SD card locks. Still observe a bug with SDIO lib which needs intermediate buffering
    [bsp.c, bsp_config.h, cpu.c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]
2013-08-08 Newer UI engine + various fixes
    [bsp.c, disp_1100.c, main.c]
2013-09-06 UI Fixes. Added auto-pause and auto-resume feature if headset is pulled out while playing
    [bsp.c, bsp_config.h, main.c]
2014-02-23 Display divided into 2 layers; bug fixes
    [bsp.c, bsp_config.h, cpu.c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]
